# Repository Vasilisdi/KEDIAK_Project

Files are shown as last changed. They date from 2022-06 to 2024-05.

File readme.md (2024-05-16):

# RISKAC Research Program - Environmental Data Collection Project

## Overview

This project, associated with the RISKAC research program, aims to collect environmental data using an electronics system comprising various components. The system is designed to measure temperature, VOC (Volatile Organic Compounds), and other environmental parameters. It utilizes a custom-designed PCB fabricated with KiCAD to provide users with a convenient "plug and play" option. Additionally, the project involves adapting source code for different sensors to meet specific project requirements.

## Tools Used

- SQL
- Python
- Arduino Programming Language
- KiCAD
- Fritzing
- PHP
- 3D Printing

## Components and Features

- **Electronic Components**: The system incorporates a variety of sensors for temperature, VOC, and other environmental data collection.
- **Custom PCB**: Designed with KiCAD, the PCB facilitates easy integration of sensors and ensures efficient communication and power supply.
- **Data Storage and Management**: Data collected by the sensors is stored in CSV files using Spyder platform. The last instance of stored data is then stored in a database for further analysis and retrieval.
- **3D-Printed Case**: A protective case with humidity-removing extruded features has been 3D-printed to safeguard electronic components and ensure reliable operation in varying environmental conditions.

## Project Progression on Kicad

The project began with a power breadboard prototype and evolved into the development of a sophisticated PCB that meets the communication and power supply needs of the integrated sensors. Below is a visual representation of the project in the KiCAD environment:


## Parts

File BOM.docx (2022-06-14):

- J1. PJ-059AH
  - https://www.cuidevices.com/product/resource/pj-059ah.pdf
- LM317_TO-220
  - Package_TO_SOT_THT:TO-220-3_Vertical
  - http://www.ti.com/lit/ds/symlink/lm317.pdf
- U1 : LM7805_TO220
  - Package_TO_SOT_THT:TO-220-3_Vertical
  - https://www.onsemi.cn/PowerSolutions/document/MC7800-D.PDF
- C1 : 10μF :
  - Capacitor_SMD: C_0805_2012Metric
  - πάνω από 12V
- C2 : 0,1 μF :
  - Capacitor_SMD: C_0805_2012Metric
  - πάνω από 5V
- C3 : 1 μF :
  - Capacitor_SMD: C_0805_2012Metric
  - πάνω από 5V
- R1 : 180Ω
  - Resistor_SMD:R_0805_2012Metric
- R2 : 330Ω
  - Resistor_SMD:R_0805_2012Metric
- R3 : 560Ω
  - Resistor_SMD:R_0805_2012Metric
- D1 : LED
  - LED_SMD:LED_0805_2012Metric
- J4 : Screw_Terminal_01x06
  - TerminalBlock:TerminalBlock_bornier-6_P5.08mm
  - https://www.snapeda.com/parts/CTB0700/3/Camden%20Boss/datasheet/
- J6 : Conn_01x03_Male
  - Connector_PinHeader_2.54mm:PinHeader_1x03_P2.54mm_Vertical
- J7 : Screw_Terminal_01x02
  - TerminalBlock:TerminalBlock_bornier-2_P5.08mm
  - https://www.snapeda.com/parts/CTB0700/3/Camden%20Boss/datasheet/
- J13 : Conn_01x04
  - Pinsockets – female
  - Connector_PinSocket_2.54mm:PinSocket_1x04_P2.54mm_Vertical
- J11 : Conn_01x12
  - Pinsockets – female
  - Connector_PinSocket_2.54mm:PinSocket_1x12_P2.54mm_Vertical
- J2 : Conn_01x7
  - Pinsockets – female
  - Connector_PinSocket_2.54mm:PinSocket_1x7_P2.54mm_Vertical
- J8 : Conn_01x5
  - Pinsockets – female
  - Connector_PinSocket_2.54mm:PinSocket_1x5_P2.54mm_Vertical
- J12 : Conn_01x4
  - Pinsockets – female
  - Connector_PinSocket_2.54mm:PinSocket_1x4_P2.54mm_Vertical
- J14 : Conn_01x4
  - Pinsockets – female
  - Connector_PinSocket_2.54mm:PinSocket_1x4_P2.54mm_Vertical
- J5 : Conn_01x4
  - Pinsockets – female
  - Connector_PinSocket_2.54mm:PinSocket_1x4_P2.54mm_Vertical
- J10 : Conn_01x4
  - Pinsockets – female
  - Connector_PinSocket_2.54mm:PinSocket_1x4_P2.54mm_Vertical
- J9 : Conn_01x7
  - Pinsockets – female
  - Connector_PinSocket_2.54mm:PinSocket_1x7_P2.54mm_Vertical
- J3 : Conn_01x8
  - Pinsockets – female
  - Connector_PinSocket_2.54mm:PinSocket_1x8_P2.54mm_Vertical

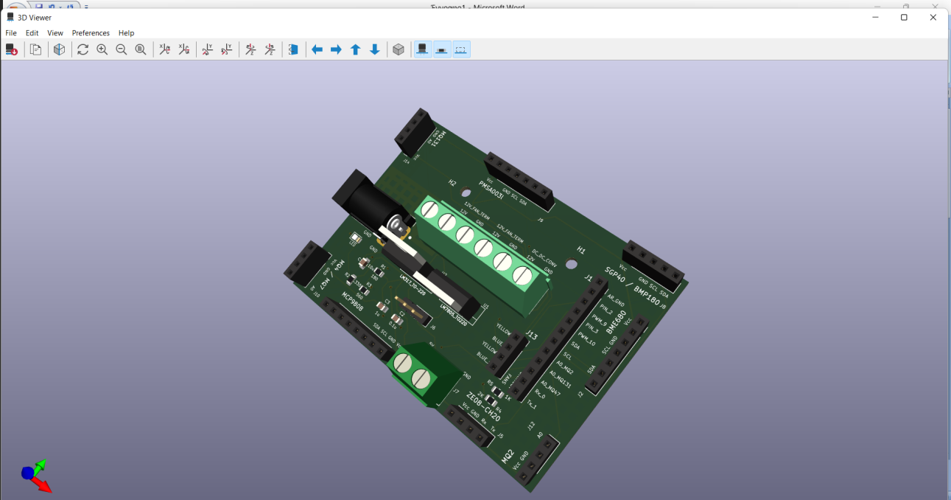
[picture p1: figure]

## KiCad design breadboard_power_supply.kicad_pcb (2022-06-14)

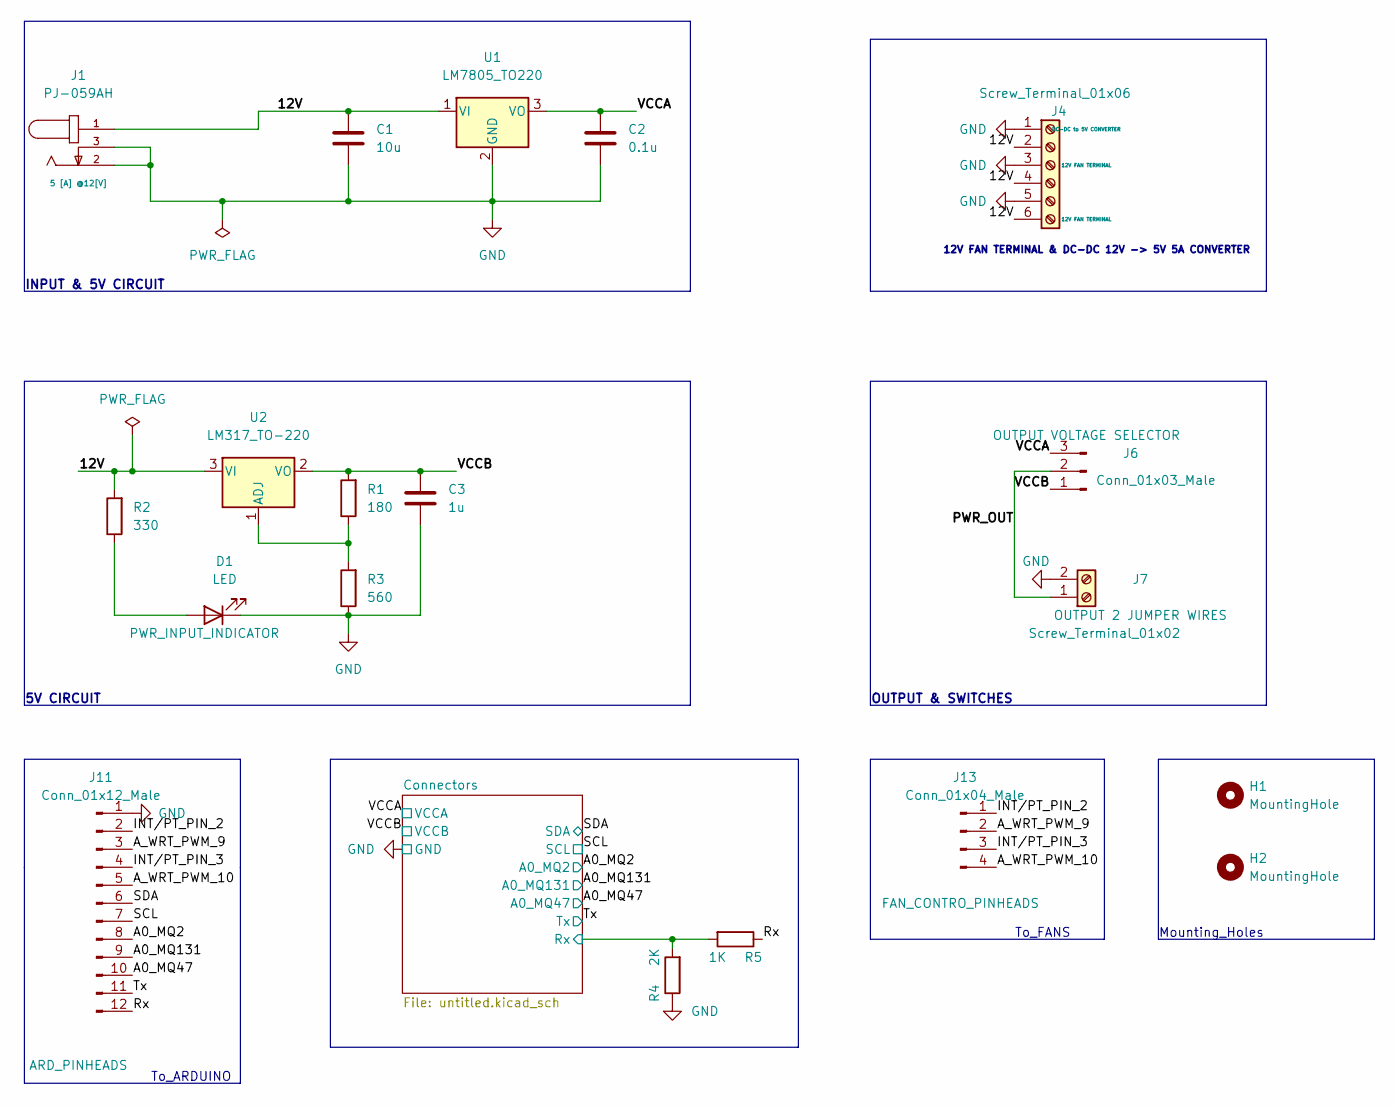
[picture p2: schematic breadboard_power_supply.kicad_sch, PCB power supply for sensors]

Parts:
C1: 10u; C_0805_2012Metric
C2: 0.1u; C_0805_2012Metric
C3: 1u; C_0805_2012Metric
D1: LED; LED_0805_2012Metric
H1, H2: MountingHole; MountingHole_2.7mm
J1: PJ-059AH; CUI_PJ-059AH; Rating 5 [A] @12[V]; PARTREV 1.02
J4: Screw_Terminal_01x06; TerminalBlock_bornier-6_P5.08mm; RATING 8 [A]
J6: Conn_01x03_Male; PinHeader_1x03_P2.54mm_Vertical
J7: Screw_Terminal_01x02; TerminalBlock_bornier-2_P5.08mm; Rating 8 [A]
J11: Conn_01x12_Male; PinSocket_1x12_P2.54mm_Vertical
J13: Conn_01x04_Male; PinSocket_1x04_P2.54mm_Vertical
R1: 180; R_0805_2012Metric
R2: 330; R_0805_2012Metric
R3: 560; R_0805_2012Metric
R4: 2K; R_0805_2012Metric
R5: 1K; R_0805_2012Metric
U1: LM7805_TO220; TO-220-3_Vertical; Rating 1 [A]
U2: LM317_TO-220; TO-220-3_Vertical; Rating 1,5 [A]

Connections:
/12V: C1.1, J1.1, J4.2, J4.4, J4.6, R2.2, U1.1 (VI), U2.3 (VI)
/A0_MQ2: J11.8; also elsewhere on the board
/A0_MQ47: J11.10; also elsewhere on the board
/A0_MQ131: J11.9; also elsewhere on the board
/A_WRT_PWM_9: J11.3, J13.2
/A_WRT_PWM_10: J11.5, J13.4
/Connectors/Rx: R4.2, R5.2; also elsewhere on the board
/INT/PT_PIN_2: J11.2, J13.1
/INT/PT_PIN_3: J11.4, J13.3
/PWR_OUT: J6.2, J7.1
/Rx: J11.12, R5.1
/SCL: J11.7; also elsewhere on the board
/SDA: J11.6; also elsewhere on the board
/Tx: J11.11; also elsewhere on the board
/VCCA: C2.1, J6.3, U1.3 (VO); also elsewhere on the board
/VCCB: C3.1, J6.1, R1.2, U2.2 (VO); also elsewhere on the board
GND: C1.2, C2.2, C3.2, D1.1 (K), J1.2, J1.3, J4.1, J4.3, J4.5, J7.2, J11.1, R3.1, R4.1, U1.2 (GND); also elsewhere on the board
unnamed: D1.2 (A), R2.1
unnamed: R1.1, R3.2, U2.1 (ADJ)

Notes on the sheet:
OUTPUT & SWITCHES
5V CIRCUIT
12V FAN TERMINAL & DC-DC 12V -> 5V 5A CONVERTER
INPUT & 5V CIRCUIT
Το_ARDUINO
Το_FANS
Mounting_Holes

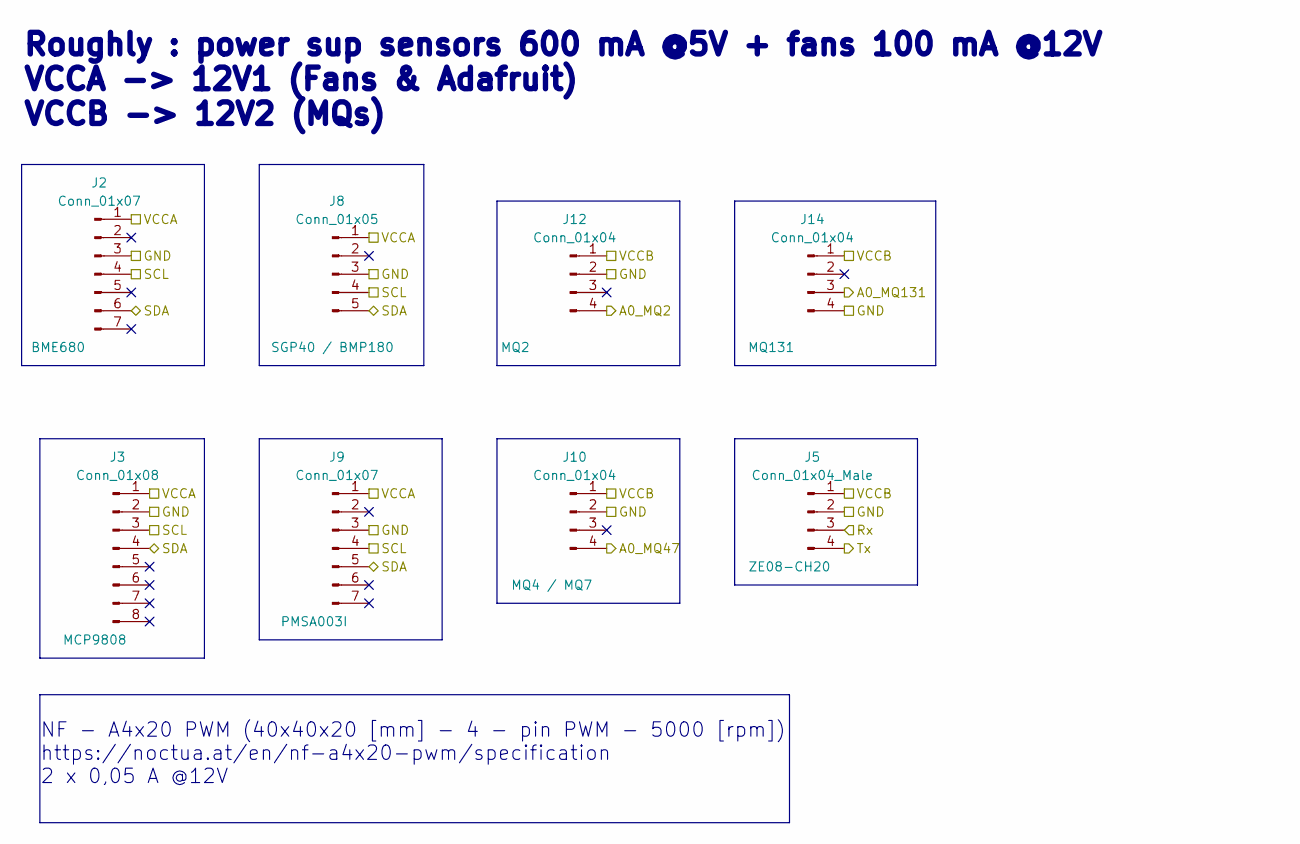
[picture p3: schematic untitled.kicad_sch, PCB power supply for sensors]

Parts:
J2, J9: Conn_01x07; PinSocket_1x07_P2.54mm_Vertical
J3: Conn_01x08; PinSocket_1x08_P2.54mm_Vertical
J5: Conn_01x04_Male; PinSocket_1x04_P2.54mm_Vertical
J8: Conn_01x05; PinSocket_1x05_P2.54mm_Vertical
J10, J12, J14: Conn_01x04; PinSocket_1x04_P2.54mm_Vertical

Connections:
/A0_MQ2: J12.4; also elsewhere on the board
/A0_MQ47: J10.4; also elsewhere on the board
/A0_MQ131: J14.3; also elsewhere on the board
/Connectors/Rx: J5.3; also elsewhere on the board
/SCL: J2.4, J3.3, J8.4, J9.4; also elsewhere on the board
/SDA: J2.6, J3.4, J8.5, J9.5; also elsewhere on the board
/Tx: J5.4; also elsewhere on the board
/VCCA: J2.1, J3.1, J8.1, J9.1; also elsewhere on the board
/VCCB: J5.1, J10.1, J12.1, J14.1; also elsewhere on the board
GND: J2.3, J3.2, J5.2, J8.3, J9.3, J10.2, J12.2, J14.4; also elsewhere on the board

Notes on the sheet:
NF - A4x20 PWM (40x40x20 [mm] - 4 - pin PWM - 5000 [rpm]) https://noctua.at/en/nf-a4x20-pwm/specification 2 x 0,05 A @12V
Roughly : power sup sensors 600 mA @5V + fans 100 mA @12V VCCA -> 12V1 (Fans & Adafruit) VCCB -> 12V2 (MQs)

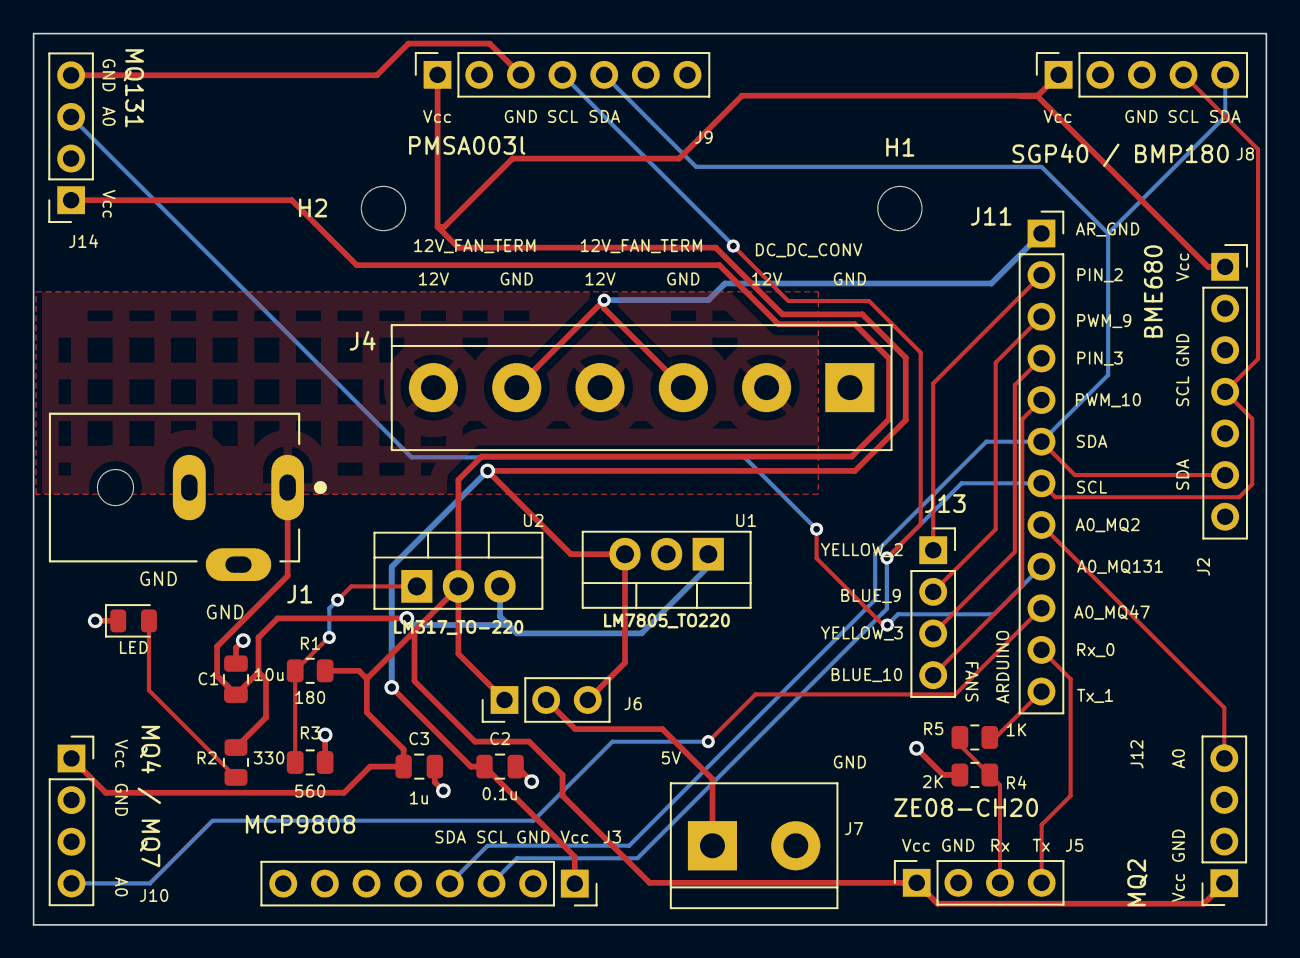
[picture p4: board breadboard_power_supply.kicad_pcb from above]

Board: 2 copper layers, 75.2 x 54.4 mm, 27 parts (0 on the bottom side), 19 nets.

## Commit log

2022-04-17 Main commission.
    [breadboard_power_supply.kicad_pcb, breadboard_power_supply.kicad_sch]
2022-04-17 PCB complete design of the power supply.
    [breadboard_power_supply.kicad_pcb]
2022-05-23 Project Target Desctription
    [breadboard_power_supply.kicad_pcb, breadboard_power_supply.kicad_sch, untitled.kicad_sch]
2022-05-23 Project Target Description
    [breadboard_power_supply.kicad_pcb, breadboard_power_supply.kicad_sch, untitled.kicad_sch]
2022-05-23 Revert "Project Target Description"
    This reverts commit 992a993e3ba41f038e621602d57108eb9190e08b.
    [breadboard_power_supply.kicad_pcb, breadboard_power_supply.kicad_sch, untitled.kicad_sch]
2022-05-24 back-up recovery
    I lost the old document, and tried to bring it back extracting a backups file from Supply_and_Sensors branch
    [breadboard_power_supply.kicad_pcb, breadboard_power_supply.kicad_sch, untitled.kicad_sch]
2022-05-24 Added some MQs
    needs to be further investigated - to check if it is worth it to install also plain MQ
    [breadboard_power_supply.kicad_sch, untitled.kicad_sch]
2022-05-25 Rearrangement
    in order to fit all the new female pin sockets and fit all into a smaller PCB
    [breadboard_power_supply.kicad_pcb, breadboard_power_supply.kicad_sch, untitled.kicad_sch]
2022-06-05 Design tweaking
    staging of all the modifications needed , in order to cover the needs of all the power board
    [breadboard_power_supply.kicad_pcb, breadboard_power_supply.kicad_sch, untitled.kicad_sch]
2022-06-05 Clear separation of 2 designs : with usb
    consumption calculation , manuals / issue with slider switch to be checked if ok
    [breadboard_power_supply.kicad_sch, untitled.kicad_sch]
2022-06-12 Design Rectified
    Added pinheads, all components and parts with their datasheets , power calculations and details - design improvement route tracks thickness check and calculation & F. silkscreening. Remaining : route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
    [breadboard_power_supply.kicad_pcb, breadboard_power_supply.kicad_sch, untitled.kicad_sch]
2022-06-12 Design Rectified
    Added pinheads & -sockets, all components and parts with their datasheets , power calculations and details - design improvement route tracks thickness check and calculation & F. silkscreening. Remain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
    [breadboard_power_supply.kicad_pcb, breadboard_power_supply.kicad_sch, untitled.kicad_sch]
2022-06-12 Remaining : route tracking
    [breadboard_power_supply.kicad_pcb, breadboard_power_supply.kicad_sch]
2022-06-13 Routing and Copper - hatch fills
    proceeding
    [breadboard_power_supply.kicad_pcb, breadboard_power_supply.kicad_sch]
2022-06-14 FINALIZING PCB DESIGN
    [breadboard_power_supply.kicad_pcb]
2022-06-14 MANUFACTURING OF THE PCB
    new path in order to keep all the details in need only
    [breadboard_power_supply-B_Cu.gbl, breadboard_power_supply-B_Mask.gbs, breadboard_power_supply-B_Paste.gbp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]
2024-05-16 Project presentation
    This document has been created so as to keep track of the project developments.
